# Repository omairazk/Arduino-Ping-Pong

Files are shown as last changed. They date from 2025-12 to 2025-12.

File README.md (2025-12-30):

# Arduino Ping Pong (Puck Game)

Two-player reaction-based electronic puck game built using Arduino Nano.

## Features
- Joystick-controlled gameplay
- Real-time score tracking with 7-segment displays
- Shift-register-based display control
- Audio feedback via buzzer
- Custom-designed PCB

## Repository Structure
- Software/ – Arduino source code
- PONG/ – Schematics, PCB layouts
- PONG_GERB/ - Drill, Gerber Files
- Datasheets/ - Parts used

## PCB Build & Assembly Instructions

This repository contains all files required to manufacture, assemble, and program the Arduino Ping Pong PCB.

### 1. PCB Manufacturing
Fabricate the PCB using the Gerber and drill files located in:
- `PONG/`
- `PONG_GERB/`

Upload these files to a standard PCB manufacturer (e.g., JLCPCB, PCBWay) using typical default settings:
- Board thickness: 1.6 mm
- Copper weight: 1 oz
- Surface finish: HASL or ENIG
- Solder mask: Any color

### 2. Required Components
- Arduino Nano
- 74HC595 shift registers
- Two joystick modules
- Two 7-segment displays
- tow Buzzer
- 330ohm Resistors (current-limiting and pull-ups as specified in schematic)
- 1 uf Capacitors (decoupling)
- Female connectors, normal and 90 degree configuration
- Solder station

### 3. Required Softwareew
- Arduino ide
- Kicad

Refer to the schematic for exact component values and connections:
- `PONG/`

### 4. PCB Assembly
1. Begin by soldering low-profile components (resistors and capacitors).
2. Solder ICs (74HC595 shift registers) and header pins.
3. Mount and solder the Arduino Nano.
4. Install the 7-segment displays, joystick connectors, and buzzer.
5. Visually inspect all solder joints for shorts, cold joints, or misalignment.

### 5. Firmware Upload
1. Connect the Arduino Nano to a computer via USB.
2. Open the Arduino IDE.
3. Load the firmware located in:
   - `Software/`
4. Select the correct board (Arduino Nano) and COM port.
5. Upload the firmware to the board.

### 6. Initial Power-On and Testing
- Power the board using USB (5 V).
- Confirm that the 7-segment displays initialize correctly.
- Verify joystick inputs respond to movement.
- Check that the buzzer activates during scoring events.

### 7. Gameplay Verification
- Ensure both players can control their Joysticks.
- Confirm scores increment correctly.
- Verify game reset and restart behavior.

Once all checks pass, the PCB is ready for normal gameplay, HAVE FUN!!

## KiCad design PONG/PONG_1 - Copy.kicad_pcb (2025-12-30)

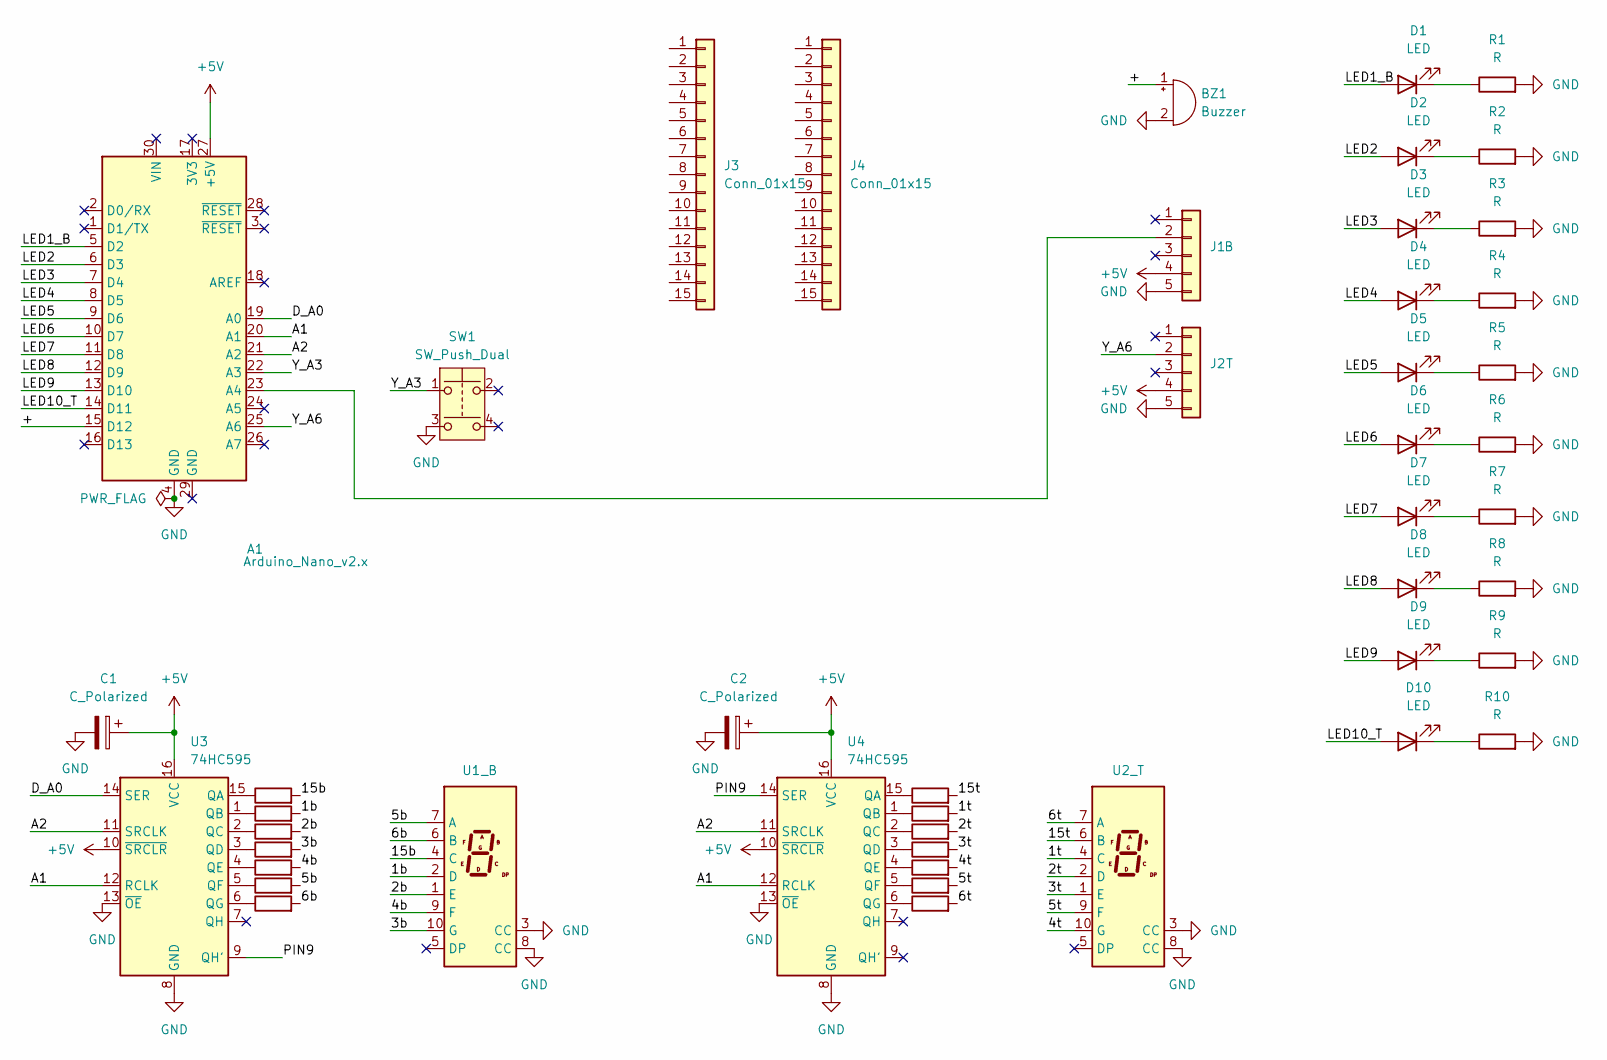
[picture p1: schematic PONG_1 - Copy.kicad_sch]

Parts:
A1: Arduino_Nano_v2.x; Arduino_Nano
BZ1: Buzzer; Buzzer_TDK_PS1240P02BT_D12.2mm_H6.5mm
C1, C2: C_Polarized; CP_Radial_D5.0mm_P2.50mm
D1, D2, D3, D4, D5, D6, D7, D8, D9, D10: LED; LED_D5.0mm
J1: B; PinSocket_1x05_P2.54mm_Horizontal
J2: T; PinSocket_1x05_P2.54mm_Horizontal
J3, J4: Conn_01x15; PinSocket_1x15_P2.54mm_Vertical
R1, R2, R3, R4, R5, R6, R7, R8, R9, R10, R11, R12, R13, R14, R15, R16, R17, R18, R19, R20, R21, R22, R23, R24: R; R_Axial_DIN0207_L6.3mm_D2.5mm_P7.62mm_Horizontal
SW1: SW_Push_Dual; SW_Push_2P1T_Toggle_CK_PVA1xxH1xxxxxxV2
U1: _B; D1X8K
U2: _T; D1X8K
U3, U4: 74HC595; DIP-16_W7.62mm

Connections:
+5V: A1.27 (+5V), C1.1, C2.1, J1.4, J2.4, U3.10 (~SRCLR), U3.16 (VCC), U4.10 (~SRCLR), U4.16 (VCC)
/1b: R12.2, U1.2 (D)
/1t: R19.2, U2.4 (C)
/2b: R13.2, U1.1 (E)
/2t: R20.2, U2.2 (D)
/3b: R14.2, U1.10 (G)
/3t: R21.2, U2.1 (E)
/4b: R15.2, U1.9 (F)
/4t: R22.2, U2.10 (G)
/5b: R16.2, U1.7 (A)
/5t: R23.2, U2.9 (F)
/6b: R17.2, U1.6 (B)
/6t: R24.2, U2.7 (A)
/15b: R11.2, U1.4 (C)
/15t: R18.2, U2.6 (B)
/+: A1.15 (D12), BZ1.1 (+)
/A1: A1.20 (A1), U3.12 (RCLK), U4.12 (RCLK)
/A2: A1.21 (A2), U3.11 (SRCLK), U4.11 (SRCLK)
/D_A0: A1.19 (A0), U3.14 (SER)
/LED1_B: A1.5 (D2), D1.2 (A)
/LED2: A1.6 (D3), D2.2 (A)
/LED3: A1.7 (D4), D3.2 (A)
/LED4: A1.8 (D5), D4.2 (A)
/LED5: A1.9 (D6), D5.2 (A)
/LED6: A1.10 (D7), D6.2 (A)
/LED7: A1.11 (D8), D7.2 (A)
/LED8: A1.12 (D9), D8.2 (A)
/LED9: A1.13 (D10), D9.2 (A)
/LED10_T: A1.14 (D11), D10.2 (A)
/PIN9: U3.9 (QH'), U4.14 (SER)
/Y_A3: A1.22 (A3), SW1.1
/Y_A6: A1.25 (A6), J2.2
GND: A1.4 (GND), BZ1.2 (-), C1.2, C2.2, J1.5, J2.5, R1.2, R2.2, R3.2, R4.2, R5.2, R6.2, R7.2, R8.2, R9.2, R10.2, SW1.3, U1.3 (CC), U1.8 (CC), U2.3 (CC), U2.8 (CC), U3.8 (GND), U3.13 (~OE), U4.8 (GND), U4.13 (~OE)
unnamed: A1.23 (A4), J1.2
unnamed: D1.1 (K), R1.1
unnamed: D2.1 (K), R2.1
unnamed: D3.1 (K), R3.1
unnamed: D4.1 (K), R4.1
unnamed: D5.1 (K), R5.1
unnamed: D6.1 (K), R6.1
unnamed: D7.1 (K), R7.1
unnamed: D8.1 (K), R8.1
unnamed: D9.1 (K), R9.1
unnamed: D10.1 (K), R10.1
unnamed: R11.1, U3.15 (QA)
unnamed: R12.1, U3.1 (QB)
unnamed: R13.1, U3.2 (QC)
unnamed: R14.1, U3.3 (QD)
unnamed: R15.1, U3.4 (QE)
unnamed: R16.1, U3.5 (QF)
unnamed: R17.1, U3.6 (QG)
unnamed: R18.1, U4.15 (QA)
unnamed: R19.1, U4.1 (QB)
unnamed: R20.1, U4.2 (QC)
unnamed: R21.1, U4.3 (QD)
unnamed: R22.1, U4.4 (QE)
unnamed: R23.1, U4.5 (QF)
unnamed: R24.1, U4.6 (QG)

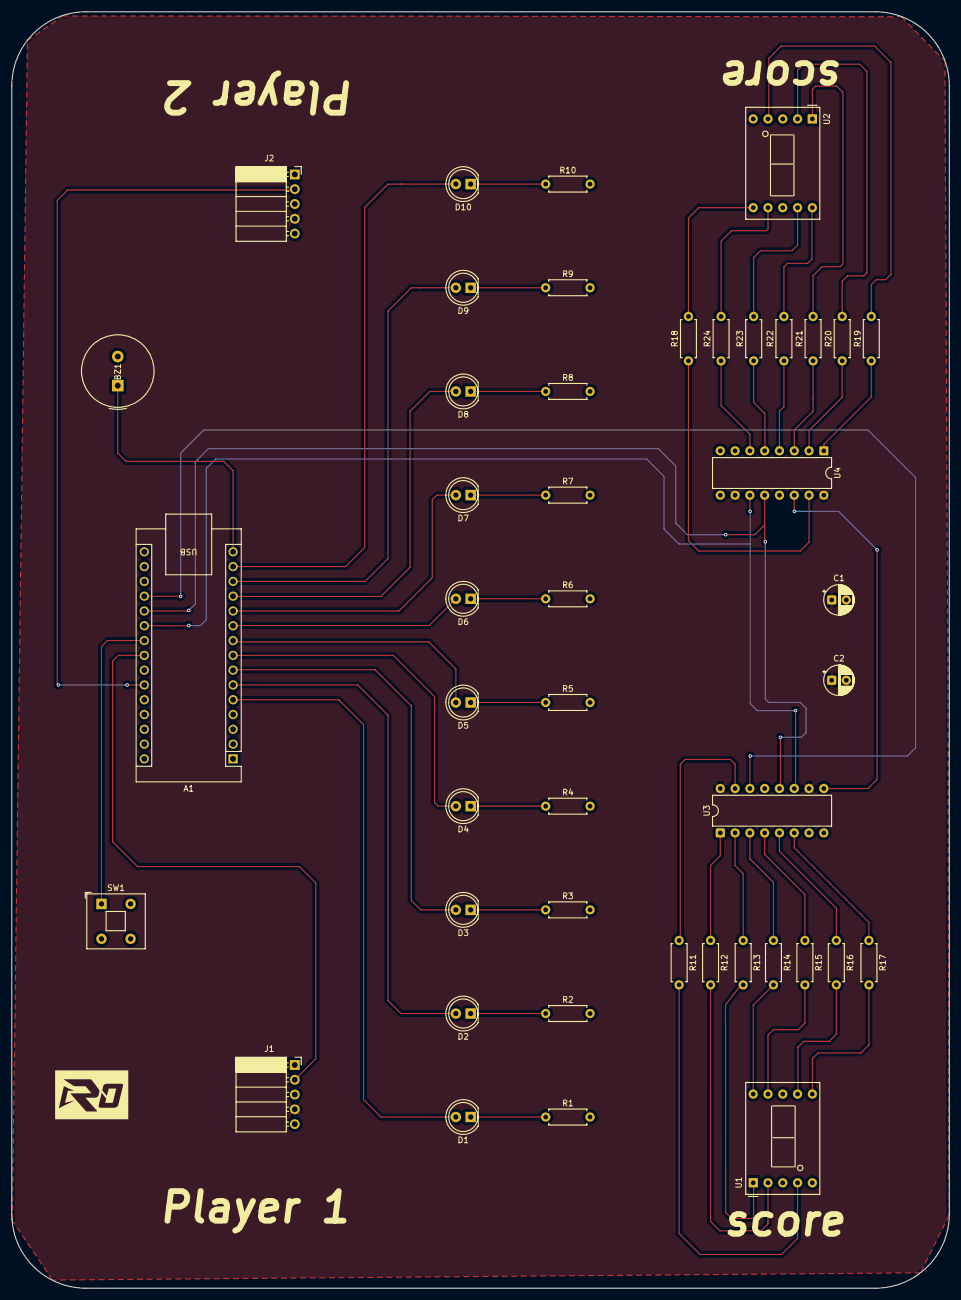
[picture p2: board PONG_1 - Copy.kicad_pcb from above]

Board: 2 copper layers, 161.0 x 219.2 mm, 45 parts (0 on the bottom side), 58 nets.

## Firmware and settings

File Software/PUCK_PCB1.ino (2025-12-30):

int buzzer = 12;

const int ardpins = 10;
int led[ardpins] = {2, 3, 4, 5, 6, 7, 8, 9, 10, 11};

int puckPos = 4;
int direction = 1;
int yPin = A4;
int yVal = 530;          // Joystick-1 center ≈770
int yp2Pin = A6;
int y2val = 659;

const int btnPin = A3;
int onswt = 1;

bool buttonState = HIGH;
bool lastButtonState = HIGH;
unsigned long lastDebounceTime = 0;
const unsigned long debounceDelay = 50;

unsigned long lastMoveTime = 0;
unsigned long lastJoystickRead = 0;
unsigned long lastJoystickRead2 = 0;

const int joystickDelay = 10;
int count1 = 0;
int count2 = 0;

// Anti-Cheat Flags
bool ready1 = false;
bool ready2 = false;

// Game timer
unsigned long gameStartTime = 0;

// Display Pins
const int dataPin = A0;
const int clockPin = A2;
const int latchPin = A1;

// Corrected digits arrays (0–9) for each display
const byte digits1[10] = {
  B1110111,  // 0
  B1000001,  // 1
  B1101110,  // 2
  B1101011,  // 3
  B1011001,  // 4
  B0111011,  // 5
  B0111111,  // 6
  B1100001,  // 7
  B1111111,  // 8
  B1111011   // 9
};

const byte digits2[10] = {
  B1101111,  // 0
  B0000011,  // 1
  B1011101,  // 2
  B1010111,  // 3
  B0110011,  // 4
  B1110110,  // 5
  B1111110,  // 6
  B1000011,  // 7
  B1111111,  // 8
  B1110111   // 9
};

void setup() {
  for (int i = 0; i < ardpins; i++) {
    pinMode(led[i], OUTPUT);
  }

  pinMode(buzzer, OUTPUT);
  pinMode(dataPin, OUTPUT);
  pinMode(clockPin, OUTPUT);
  pinMode(latchPin, OUTPUT);
  pinMode(yPin, INPUT);
  pinMode(btnPin, INPUT_PULLUP);

  Serial.begin(9600);
  Serial.println("Joystick1\tJoystick2\tPuckPos\tDirection");

  displayScores(count2, count1);
}

void loop() {
  unsigned long currentTime = millis();

  // Toggle Button
  int reading = digitalRead(btnPin);
  if (reading != lastButtonState) {
    lastDebounceTime = currentTime;
  }

  if ((currentTime - lastDebounceTime) > debounceDelay) {
    if (reading == LOW && buttonState == HIGH) {
      onswt++;
      Serial.print("Toggled game. onswt = ");
      Serial.println(onswt);

      if (onswt % 2 == 1) {
        puckPos = 4;
        direction = 1;
        count1 = 0;
        count2 = 0;
        ready1 = false;
        ready2 = false;
        gameStartTime = millis();
        displayScores(count2, count1);
      }
    }
    buttonState = reading;
  }
  lastButtonState = reading;

  if (onswt % 2 == 0) {
    for (int i = 0; i < ardpins; i++) {
      digitalWrite(led[i], LOW);
    }

    digitalWrite(latchPin, LOW);
    shiftOut(dataPin, clockPin, MSBFIRST, 0);
    shiftOut(dataPin, clockPin, MSBFIRST, 0);
    digitalWrite(latchPin, HIGH);

    return;
  }

  // --- Joystick reads with live output ---
  if (currentTime - lastJoystickRead >= joystickDelay) {
    lastJoystickRead = currentTime;
    yVal = analogRead(yPin);
    Serial.print("P1: ");
    Serial.print(yVal);
    Serial.print("\t");
  }

  if (currentTime - lastJoystickRead2 >= joystickDelay) {
    lastJoystickRead2 = currentTime;
    y2val = analogRead(yp2Pin);
    Serial.print("P2: ");
    Serial.println(y2val);
  }
  // ---------------------------------------

  // Anti-cheat readiness (Player 1 centered ~770)
  if (yVal < 650) ready1 = true;       // pull back to arm
  if (y2val > 500) ready2 = true;

  // Speed curve based on time
  unsigned long elapsed = currentTime - gameStartTime;
  int dynamicDelay = 50;
  if (elapsed > 5000) dynamicDelay = 40;
  if (elapsed > 10000) dynamicDelay = 30;
  if (elapsed > 20000) dynamicDelay = 20;
  if (elapsed > 25000) dynamicDelay = 18;

  if (currentTime - lastMoveTime >= dynamicDelay) {
    lastMoveTime = currentTime;

    for (int i = 0; i < ardpins; i++) {
      digitalWrite(led[i], LOW);
    }

    digitalWrite(led[puckPos], HIGH);

    // Player 1 hit check using new center
    if (puckPos == 1 && direction == -1 && yVal > 600 && ready1) {
      direction = 1;
      ready1 = false;
    }
    else if (puckPos == 8 && direction == 1 && y2val < 300 && ready2) {
      direction = -1;
      ready2 = false;
    }
    else if (puckPos == ardpins - 1) {
      direction = -1;
    }
    else if (puckPos == 0) {
      direction = 1;
    }

    if (puckPos == 9 && count1 < 10) {       // allow 0–9 display
      count1++;
      playScoreSound();
      displayScores(count2, count1);
    }

    if (puckPos == 0 && count2 < 10) {
      count2++;
      playScoreSound();
      displayScores(count2, count1);
    }

    puckPos += direction;
    if (puckPos < 0) puckPos = 0;
    if (puckPos >= ardpins) puckPos = ardpins - 1;
  }
}

void displayScores(int p2, int p1) {
  digitalWrite(latchPin, LOW);
  shiftOut(dataPin, clockPin, MSBFIRST, digits2[p2]);
  shiftOut(dataPin, clockPin, MSBFIRST, digits1[p1]);
  digitalWrite(latchPin, HIGH);
}

void playScoreSound() {
  tone(buzzer, 800, 100); delay(120);
  tone(buzzer, 1000, 100); delay(120);
  tone(buzzer, 1200, 100); delay(200);
  noTone(buzzer);
}
